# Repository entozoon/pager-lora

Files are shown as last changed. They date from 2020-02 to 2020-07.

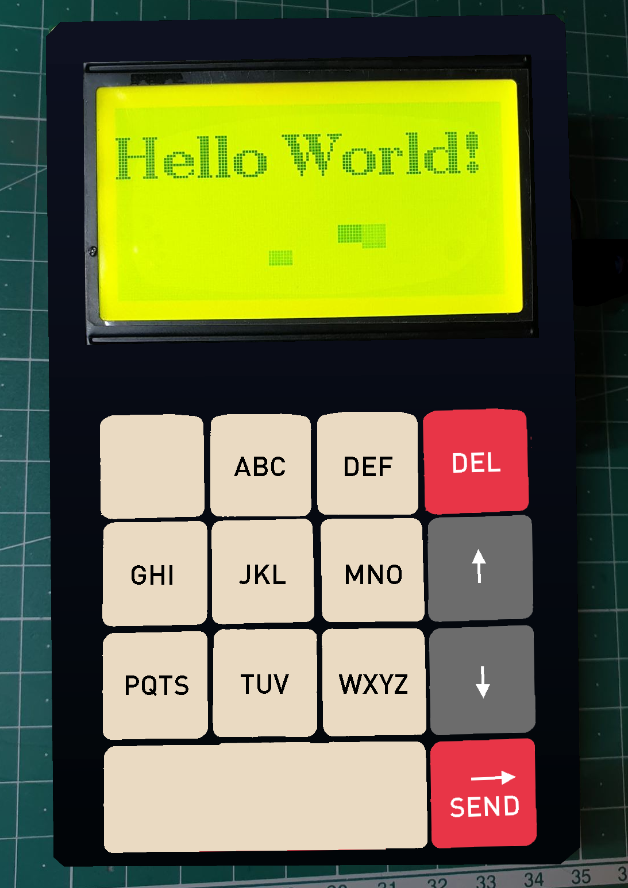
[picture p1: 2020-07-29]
mk-ii-chokia/hardware/design-1.png

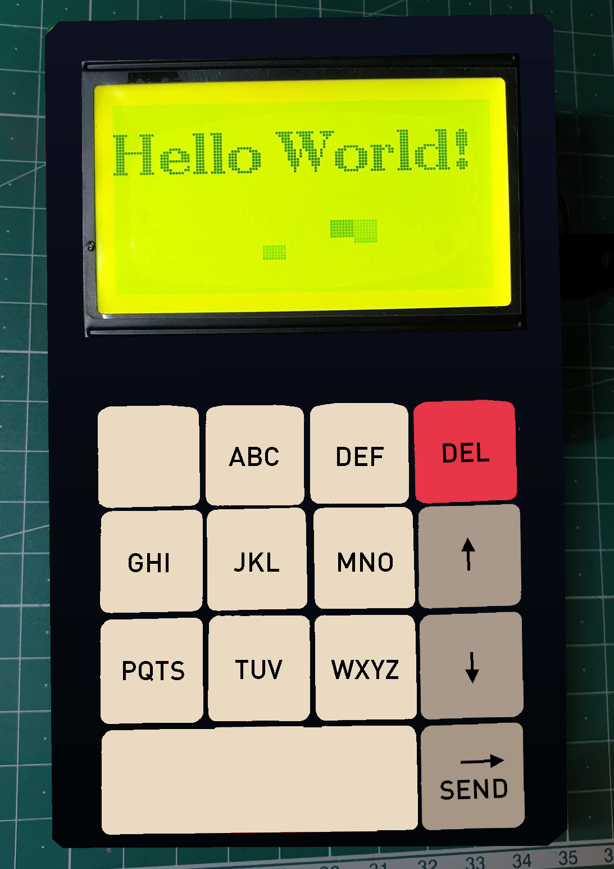
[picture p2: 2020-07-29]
mk-ii-chokia/hardware/design-5.png

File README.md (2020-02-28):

# Pager Lora

## Ingredients

- Arduino / ESP8266 ?
  Arduino is more conservative but doesn't seem to be the popular choice. I mean, speed might be an issue with transmission so bang it out on a Wemos with WIFI disabled.

## Goals

- Clamshell
- Nokia 5110 screen / e-ink
- Buzz tune on receipt
- Opening wakes up device screen
- Small as poss, but poss 18520 batteries, so..
- Lora communication over 300m

## Input

Mobile keypad text is a fun way to go. Revive that old skill.

### Drawing?

Would be nice, but bandwidth is limited, as well as rendering capabilities so.. it'd be a whole thing. Couldn't be real-time.. but still an option if I make a larger device.

## Comms

| Send Device | Listen Device | User |
| --- | :---: | ---: |
| Listening always | Listening always | |
| | | |
| Emit (n?) | | Send |
| | Receive | Buzz |
| | Store to EEPROM | |
| | Emit message received? meh | |
| Stop emitting | | |
| | Screen on, display message | Open device |
| | | |

## Power

The power concerns are real. So let's make sure to do all dis:

### Disable WIFI on microcontroller

`WiFi.mode(WIFI_OFF);`

### Sleep

If possible, I mean perhaps it could sleep half the time? Let's have a shufty at some power requirements. Complete conjecture, but anyways:

- Microcontroller
  General: 20mA ESP w/out WIFI or 5mA for pro mini
  Sleep: Negligible

- LoRa (3.3v)
  Receiver: ≦ 10mA (LnaBoost off, band 1)
  Transmit: ≦ 120mA (+ 20dBm)
  Sleep: Negligible
  Total, if listening always and transmitting like 1% of the time: 11mA

- Screen
  Unlit: 1mA
  Backlit: <= 80mA, so maybe don't bother!

- 18650 2400mah 3.7v
  5v converters are supposedly 90% efficient so 2160mAh

So, assuming they're always listening and transmit at glorious 28.8kbps modem style speed now and then:

    Battery capacity (mA/h) / Current draw (mA) = hours of battery life  .. right?

    2160mAh / 32mA = 67 hours
    900mAh / 32mA = 28 hours
    240mAh / 32mA = 7.5 hours

Woah. I mean, these are conservative numbers too. Not three bad.
So yeah, sleep both chips if possible when closed and poss use an Arduino (5mA).

### C rating?

Literally anything is fine.
Peak current, with lit screen and full transmit is like 220mA, so 0.5C @ 500mA is enough. (18650 are 1C)

### Sleep LoRa chip

Just a reminder to sleep this along with the microcontroller.

## Battery

5V step ups bitch out under .5v, which won't matter much, but the efficiency varies with input voltage (and current): http://www.hobbytronics.co.uk/u1v10f5-5v-regulator

| Battery | V |  mAh | Effic | ->~mAh | Life(h) mAh/32mA | Notes |
| --- | ---: | ---: | ----: | -----: | ---: | --- |
| AAA (r/c) | 1.5v | 1000 |  @70% | 700 | 22 | |
| AAA (r/c) x2 | 1.5v | 2000 |  @70% | 1400 | 44 | |
| AA (r/c) | 1.5v | 2400 |  @70% | 1680 | 53 | |
| Lipo 50x30mm | 3.7v | 2000 |  @90% | 1800 | 56 | Better form factor than AA |
| 18650 | 3.7v | 2400 |  @90% | 2160 | 66 | All lipos easy to charge |
| Lipo 90x60mm | 3.7v | 4000 |  @90% | 3600 | 113 | Phone bat size, affordable |

Lipo batteries supposedly self-disarge at only 5%/month (despite my experience), not far off alkaline.
So any lipo really, high mAh as possible for the best form factor.
But deeefinitely invest in a voltmeter setup (see below). Perhaps flash the screen hard and/or chirp for a turn off.

## Battery monitoring

Feed battery into analogue input, with a voltage divider to reduce it.

Wemos A0 has a voltage divider built in. 220k / 100k (2/3rdsness).
People say it has a range of 3.3V, but I should test that.

    +++++++++
        |
      [10k]
        |
        |----(100pF -> 1nF)---> analogue input
        |    reduce wobble? Didn't work..
        |
      [10k]
        |
    ---------

    V divideness = (R1 / R1 + R2)
                 = 1 / 2

So if my lipo spits out a mad 4.6V, A0 would receive 2.3V.
Update: 1024 max value is 6.1V, in reality, through my divider.

| Lipo V | Desc | Dividered | A0 (theory) | Human  |
| --- | --- | ---: | ---: | --- |
| 4.6 | Pumped | 2.3 | 713 | 100% |
| 4.2 | Full | 2.1 | 652 | 100% |
| 4 | Good | 2 | 621 | 75% |
| 3.86 | Mid | 1.93 | 599 | 50% |
| 3.75 | Low | 1.875 | 582 | 20% !  |
| 3.7 | Low | 1.85 | 574 | 10% !  |
| 3.5 | Dead | 1.75 | 543 | 0% off |

    A0 (theory) = Dividered V / 3.3 * 1024

Empirical realities are close but a little different:

| Lipo V | Desc | A0 (theory) | Human  |
| --- | --- | ---: | --- |
| 4.6 | Pumped | 762 | 100% |
| 4.2 | Full | 706 | 100% |
| 4 | Good | 660 | 75% |
| 3.86 | Mid | 634 | 50% |
| 3.75 | Low | 615 | 20% !  |
| 3.7 | Low | 608 | 10% !  |
| 3.5 | Dead | 577 | 0% off |

## Power off

It really should power itself off, LoRa et al, with low batt for safety. Might not be worth it though, I mean, do my charge protection circuits handle that? Probs eh?

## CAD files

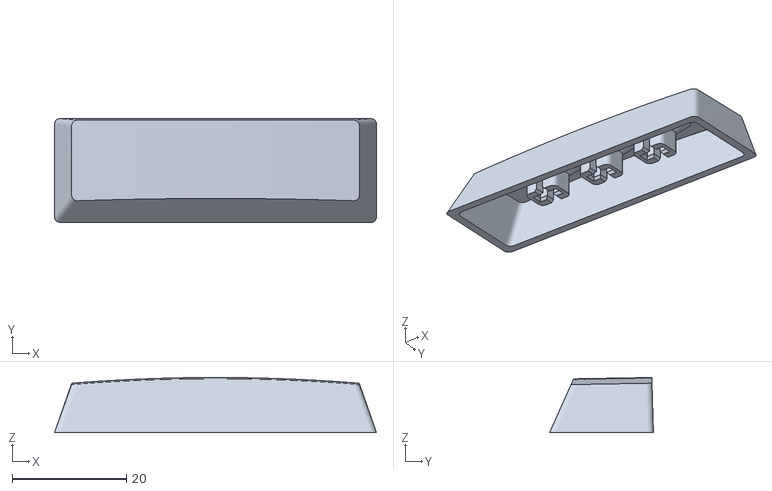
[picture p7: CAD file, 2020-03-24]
mk-ii-chokia/hardware/keycaps/chokia-spacebar.stl
56.3 x 18.2 x 9.62

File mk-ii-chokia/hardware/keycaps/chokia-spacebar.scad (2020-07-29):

// the point of this file is to be a sort of DSL for constructing keycaps.
// when you create a method chain you are just changing the parameters
// key.scad uses, it doesn't generate anything itself until the end. This
// lets it remain easy to use key.scad like before (except without key profiles)
// without having to rely on this file. Unfortunately that means setting tons of
// special variables, but that's a limitation of SCAD we have to work around

use <src/key.scad>

include <src/settings.scad>
include <src/key_sizes.scad>
include <src/key_profiles.scad>
include <src/key_types.scad>
include <src/key_transformations.scad>

//https://github.com/rsheldiii/KeyV2/blob/master/src/settings.scad

//$has_brim=true;
$inverted_dish = true;
$key_length = 3;
$stem_inset = 2;

$key_shape_type = "rounded_square"; // iso_enter sculpted_square rounded_square square oblong

$stabilizer_type = "cherry_stabilizer"; // [costar_stabilizer, cherry_stabilizer, disable]

// be reet, use the outside two?
// $stabilizers = $key_length >= 6 ? [[-50, 0], [50, 0]] : $key_length >= 2 ? [[-12,0],[12,0]] : [];

//$rounded_key = true; // good but intense

 dcs_row(1) {
     $dish_type =  "sideways cylindrical";
     key();
 }

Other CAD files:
mk-ii-chokia/hardware/keycaps/src/settings.scad
mk-ii-chokia/hardware/keycaps/customizer.scad
mk-ii-chokia/hardware/keycaps/customizer_base.scad
mk-ii-chokia/hardware/keycaps/key_mold.scad
mk-ii-chokia/hardware/keycaps/keys.scad
mk-ii-chokia/hardware/keycaps/keysets.scad
mk-ii-chokia/hardware/keycaps/model_base.scad
mk-ii-chokia/hardware/keycaps/src/dishes.scad
mk-ii-chokia/hardware/keycaps/src/dishes/cylindrical.scad
mk-ii-chokia/hardware/keycaps/src/dishes/old_spherical.scad
mk-ii-chokia/hardware/keycaps/src/dishes/sideways_cylindrical.scad
mk-ii-chokia/hardware/keycaps/src/dishes/spherical.scad
mk-ii-chokia/hardware/keycaps/src/features/key_bump.scad
mk-ii-chokia/hardware/keycaps/src/functions.scad
mk-ii-chokia/hardware/keycaps/src/key.scad
mk-ii-chokia/hardware/keycaps/src/key_features.scad
mk-ii-chokia/hardware/keycaps/src/key_profiles.scad
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

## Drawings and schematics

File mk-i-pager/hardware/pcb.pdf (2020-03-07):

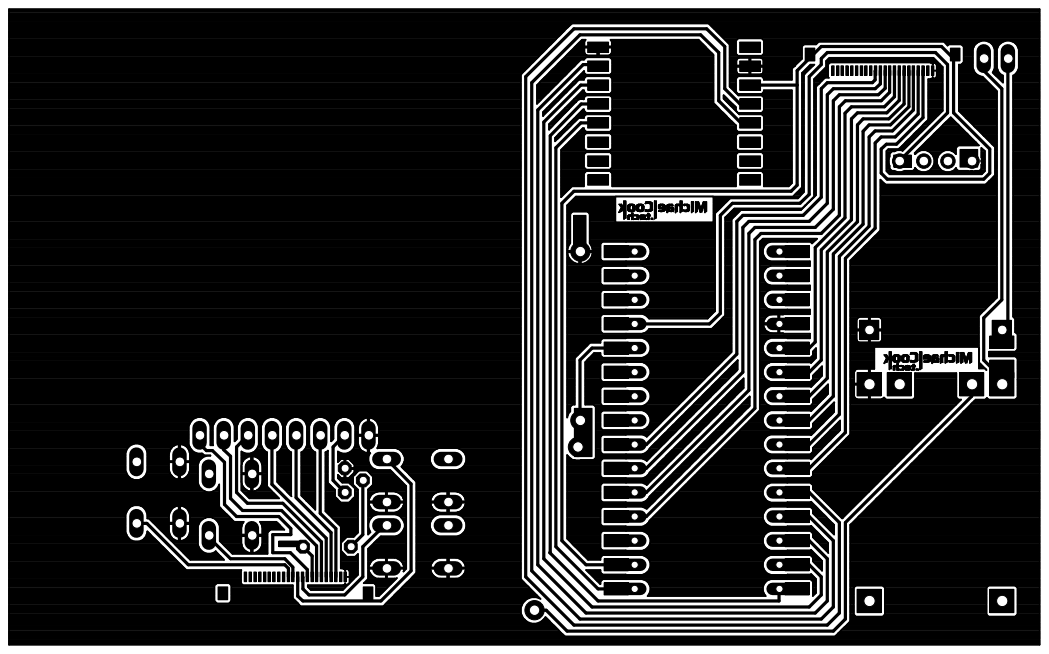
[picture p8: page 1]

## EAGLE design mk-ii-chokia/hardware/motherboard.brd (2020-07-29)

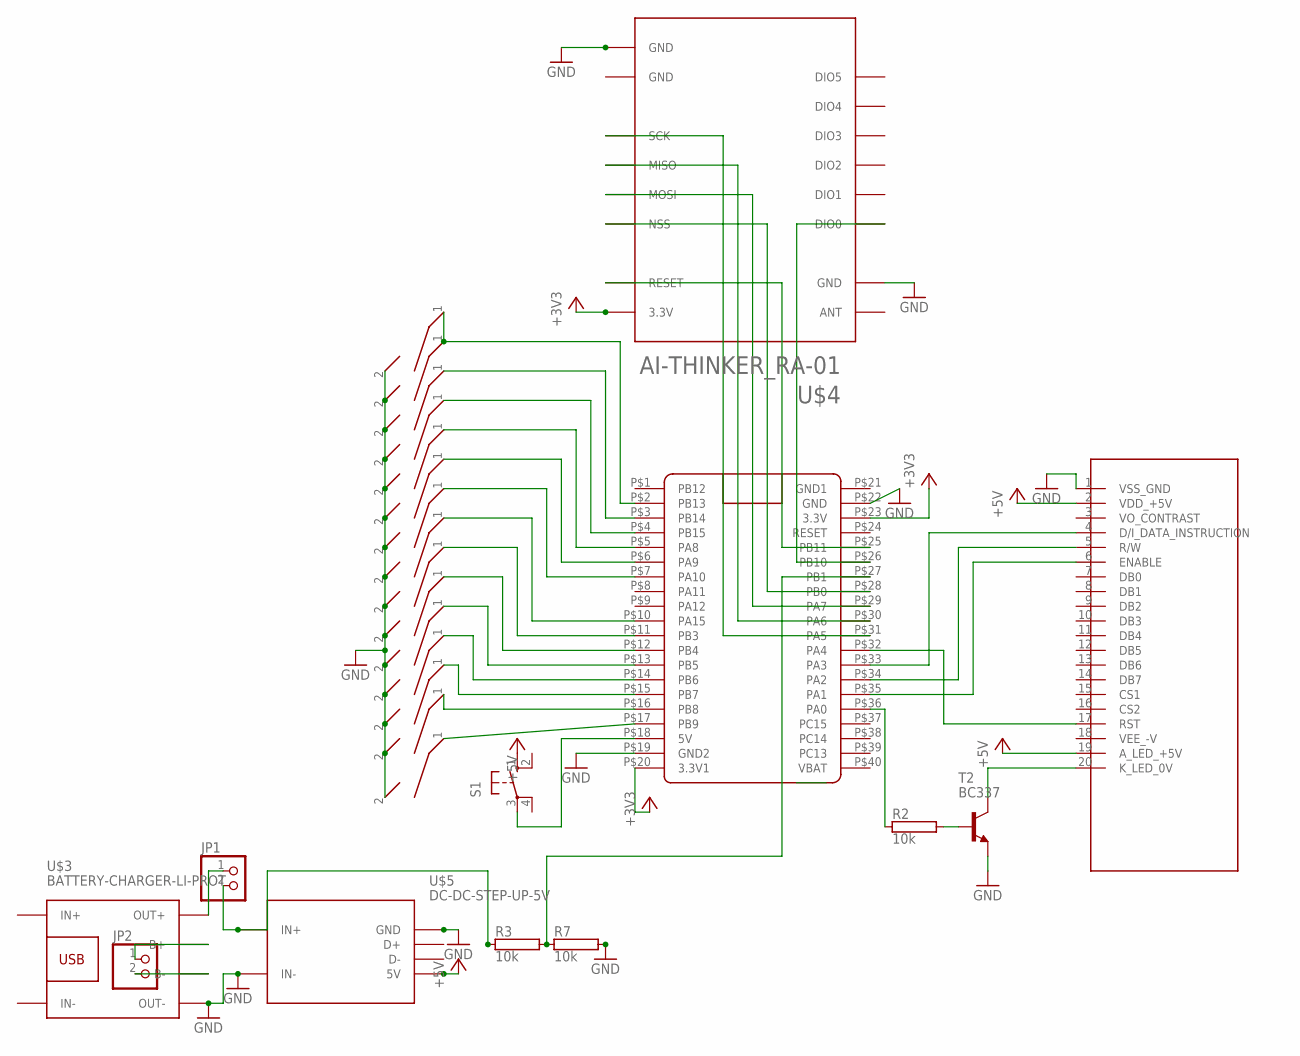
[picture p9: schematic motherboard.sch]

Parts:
JP1, JP2: PINHD-1X2/90; 1X02/90
R2, R3, R7: 10k; AC01
S1: 10-XX; B3F-10XX
SW1, SW2, SW3, SW4, SW5, SW6, SW7, SW8, SW9, SW10, SW11, SW12, SW13, SW14, SW15: CHERRY_MX; MX1A-XXNN
T2: BC337; TO92
U$1: W12864
U$2: BLUE_PILL
U$3: BATTERY-CHARGER-LI-PROT
U$4: AI-THINKER_RA-01
U$5: DC-DC-STEP-UP-5V

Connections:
+3V3: U$2.P$20 (3.3V1), U$2.P$23 (3.3V), U$4.P$3 (3.3V)
+5V: S1.1 (S), U$1.2 (VDD_+5V), U$1.19 (A_LED_+5V), U$5.5V
GND: R7.2, SW1.2, SW2.2, SW3.2, SW4.2, SW5.2, SW6.2, SW7.2, SW8.2, SW9.2, SW10.2, SW11.2, SW12.2, SW13.2, SW14.2, SW15.2, T2.1 (E), U$1.1 (VSS_GND), U$2.P$19 (GND2), U$2.P$22 (GND), U$3.OUT-, U$4.P$2 (GND), U$4.P$16 (GND), U$5.GND, U$5.IN-
GND1: U$2.P$21 (GND1)
unnamed: JP1.1, U$3.OUT+
unnamed: U$2.P$25 (PB11), U$4.P$4 (RESET)
unnamed: U$2.P$28 (PB0), U$4.P$15 (NSS)
unnamed: U$2.P$29 (PA7), U$4.P$14 (MOSI)
unnamed: U$2.P$30 (PA6), U$4.P$13 (MISO)
unnamed: U$2.P$31 (PA5), U$4.P$12 (SCK)
unnamed: U$2.P$26 (PB10), U$4.P$5 (DIO0)
unnamed: U$1.6 (ENABLE), U$2.P$35 (PA1)
unnamed: U$1.5 (R/W), U$2.P$34 (PA2)
unnamed: U$1.17 (RST), U$2.P$32 (PA4)
unnamed: U$1.4 (D/I_DATA_INSTRUCTION), U$2.P$33 (PA3)
unnamed: R2.2, T2.2 (B)
unnamed: T2.3 (C), U$1.20 (K_LED_0V)
unnamed: SW1.1, U$2.P$17 (PB9)
unnamed: JP1.2, R3.1, U$5.IN+
unnamed: SW2.1, U$2.P$16 (PB8)
unnamed: R2.1, U$2.P$36 (PA0)
unnamed: SW3.1, U$2.P$15 (PB7)
unnamed: SW4.1, U$2.P$14 (PB6)
unnamed: SW5.1, U$2.P$13 (PB5)
unnamed: SW6.1, U$2.P$12 (PB4)
unnamed: SW7.1, U$2.P$11 (PB3)
unnamed: R3.2, R7.1, U$2.P$27 (PB1)
unnamed: SW8.1, U$2.P$10 (PA15)
unnamed: SW9.1, U$2.P$7 (PA10)
unnamed: SW10.1, U$2.P$6 (PA9)
unnamed: SW13.1, U$2.P$3 (PB14)
unnamed: SW14.1, SW15.1, U$2.P$2 (PB13)
unnamed: SW11.1, U$2.P$5 (PA8)
unnamed: SW12.1, U$2.P$4 (PB15)
unnamed: JP2.1, U$3.B+
unnamed: JP2.2, U$3.B-
unnamed: S1.3, U$2.P$18 (5V)

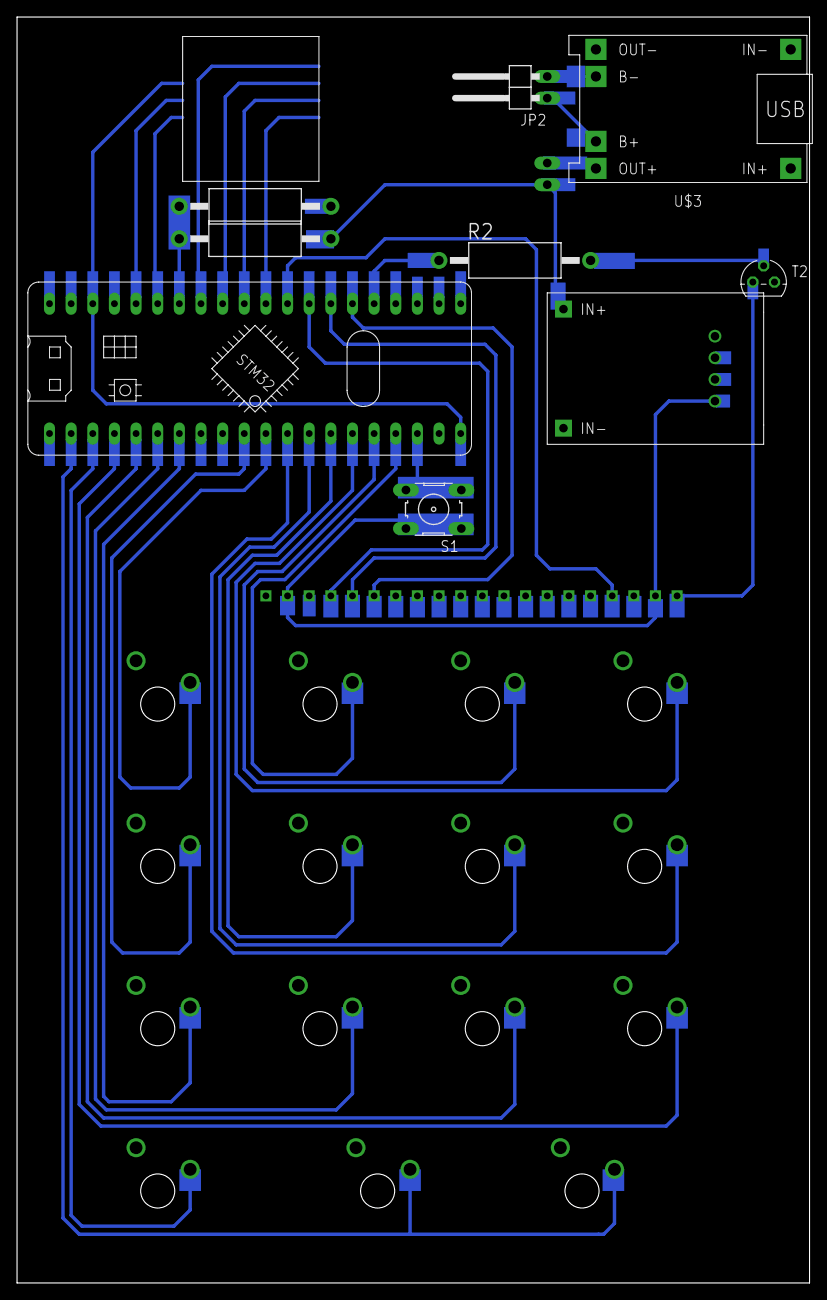
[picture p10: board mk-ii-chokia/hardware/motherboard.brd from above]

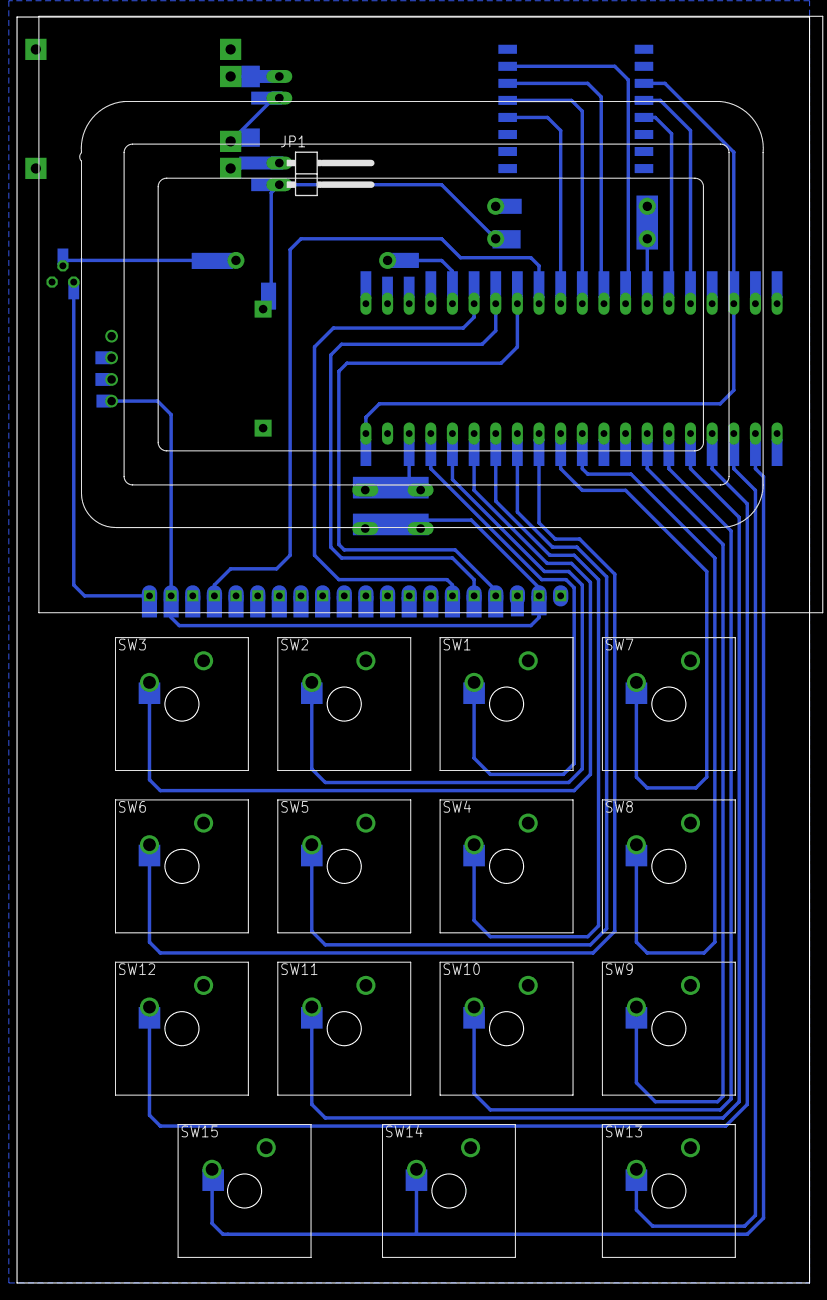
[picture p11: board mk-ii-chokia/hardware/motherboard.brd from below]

Board: 2 copper layers, 93.0 x 148.6 mm, 27 parts (17 on the bottom side), 36 nets.

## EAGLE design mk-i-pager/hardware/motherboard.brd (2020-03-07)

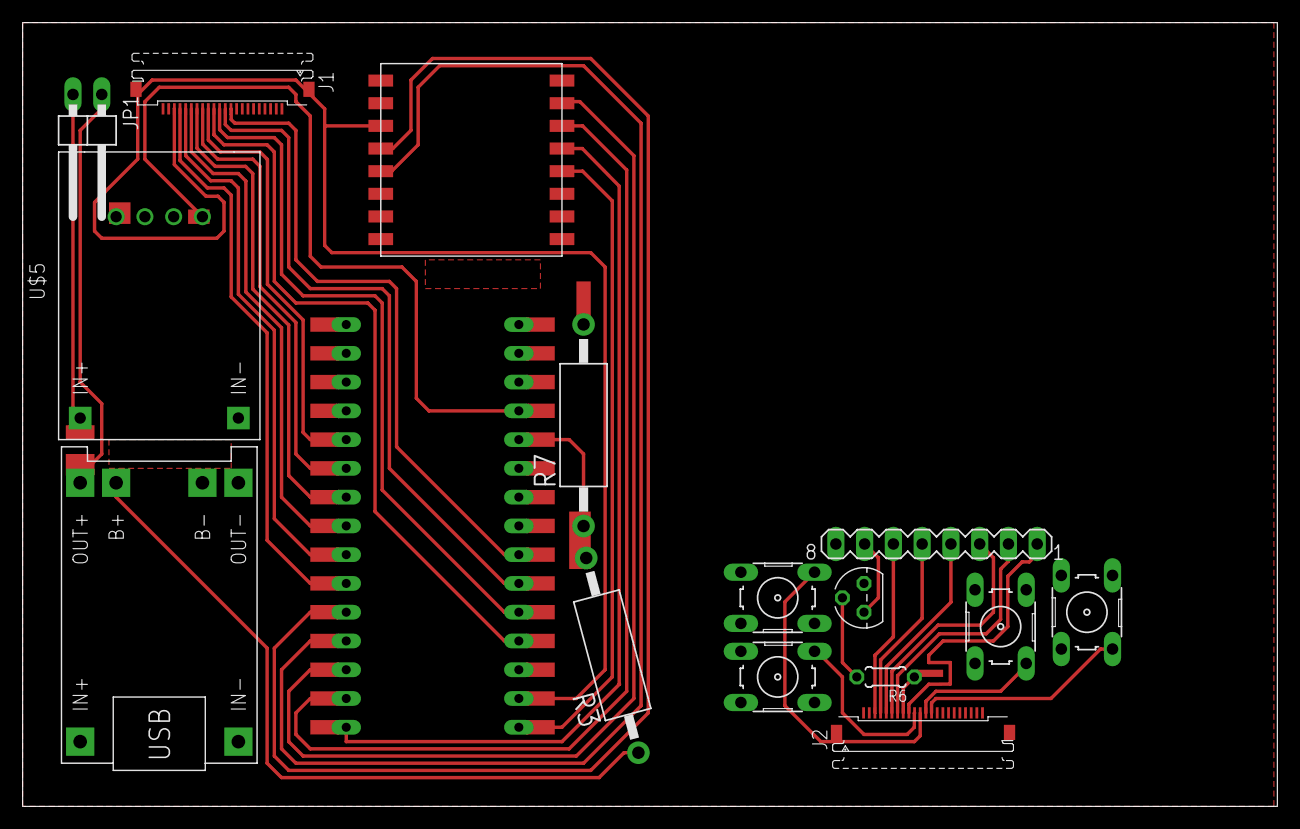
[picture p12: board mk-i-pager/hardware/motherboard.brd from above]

Board: 2 copper layers, 110.8 x 69.2 mm, 16 parts (0 on the bottom side), 36 nets.

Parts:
DIS2: NOKIA5110
J1, J2: XF2L-2235-1
JP1: 1X02/90
R3, R7: 10k; AC01
R6: 10k; 0204/5
S1, S2, S3, S4: B3F-10XX
T1: BC337; TO92
U$1: NANO
U$3: BATTERY-CHARGER-LI-PROT
U$4: AI-THINKER_RA-01
U$5: DC-DC-STEP-UP-5V

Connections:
+3V3: J1.20, U$1.3.3V, U$4.P$3
+5V: U$1.5V, U$5.5V
GND: DIS2.8, J1.22, J2.1, R7.2, S1.1, S1.2, S2.1, S2.2, S3.1, S3.2, S4.1, S4.2, T1.1, U$1.GND1, U$3.OUT-, U$4.P$2, U$4.P$16, U$5.GND, U$5.IN-
unnamed: JP1.1, U$3.OUT+
unnamed: U$1.D13, U$4.P$12
unnamed: J1.19, U$1.D7
unnamed: U$1.D12, U$4.P$13
unnamed: U$1.D11, U$4.P$14
unnamed: U$1.D10, U$4.P$15
unnamed: U$1.D9, U$4.P$5
unnamed: U$1.D8, U$4.P$4
unnamed: J1.14, U$1.D2
unnamed: J1.18, U$1.D6
unnamed: J1.17, U$1.D5
unnamed: J1.16, U$1.D4
unnamed: J1.15, U$1.D3
unnamed: R6.2, T1.2
unnamed: JP1.2, U$5.IN+
unnamed: R3.1, U$3.B+
unnamed: DIS2.1, J2.9
unnamed: J2.8, R6.1
unnamed: J2.10, S1.3
unnamed: J2.11, S2.3
unnamed: J2.12, S3.3
unnamed: DIS2.7, T1.3
unnamed: R3.2, R7.1, U$1.A7
unnamed: DIS2.6, J2.3
unnamed: DIS2.5, J2.4
unnamed: DIS2.4, J2.5
unnamed: DIS2.3, J2.6
unnamed: DIS2.2, J2.7
unnamed: J2.13, S4.3
unnamed: J1.13, U$1.A0
unnamed: J1.12, U$1.A1
unnamed: J1.11, U$1.A2
unnamed: J1.10, U$1.A3

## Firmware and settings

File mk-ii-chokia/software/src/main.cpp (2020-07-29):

#include <Arduino.h>
#include <U8g2lib.h>
#include <SPI.h>
#include <Wire.h>

// //
// // BLINK
// //
// void setup()
// {
//   pinMode(LED_BUILTIN, OUTPUT);
// }
// void loop()
// {
//   digitalWrite(LED_BUILTIN, HIGH); // turn the LED on (HIGH is the voltage level)
//   delay(200);                      // wait for a second
//   digitalWrite(LED_BUILTIN, LOW);  // turn the LED off by making the voltage LOW
//   delay(200);                      // wait for a second
// }

//
// LCD Test
//
U8G2_ST7920_128X64_1_SW_SPI u8g2(
    U8G2_R0, // rotation
    PA1,     // Clock "E" enable?
    PA2,     // Data "R/W" might have this and next wrong way.. but meh
    PA3,     // CS "RS" "D"
    PA4      // Reset "RST"
);
// Also connect +5v to VCC, BLA
// and - to GND, PSB, BLK
void setup(void)
{
  delay(10000);         // ALWAYS delay or it can't be reprogrammed easily. Press reset during build
  pinMode(PA0, OUTPUT); // dim
  u8g2.begin();
}
void loop(void)
{
  analogWrite(PA0, 255);
  u8g2.firstPage();
  do
  {
    // https://github.com/olikraus/u8g2/wiki/u8g2reference
    u8g2.setFont(u8g2_font_ncenB14_tr);
    u8g2.drawStr(0, 24, "Hello World!");
    // Can't bleeding get it to output a random string
    // char alphabet[] = {"ABCDEFGHIJKLMNOPQRSTUVWXYZ"};
    // char char_array[] = {""};
    // char_array[0] = char(random(0, 9));
    // // strcpy(char_array, alphabet[random(0, 25)].c_str());
    // u8g2.drawStr(40, 50, char_array);
    u8g2.drawBox(random(0, 100), random(30, 50), 8, 8);
    // Not amazing, then again I've no idea what the page system is so..
  } while (u8g2.nextPage());
}

// //
// // Backlight dimming test
// //
// void setup()
// {
//   Serial.begin(9600);
//   delay(10000); // ALWAYS delay or it can't be reprogrammed easily. Press reset during build
//   pinMode(PA0, OUTPUT);
// }
// float x = 0;
// float pi = 3.141592;
// void loop()
// {
//   // if (x > 255)
//   //   x = 0;
//   // Serial.print(x);
//   // Serial.print(' ');
//   // analogWrite(9, x);
//   // delay(20);
//   // x++;
//   if (x > 4 * pi)
//     x = 0;
//   int y = floor(255 * ((sin(x / 2 - pi / 2)) / 2 + .5));
//   // Serial.print(y);
//   // Serial.print(' ');
//   analogWrite(PA0, y);
//   x += 0.01;
//   delay(5);
// }

// //
// // RECEIVE
// //
// #include <SPI.h>
// #include <LoRa.h>
// void setup()
// {
//   Serial.begin(9600);
//   delay(10000); // for uploading to device
//   Serial.println("\nLoRa Receiver");
//   //          (nss, reset, dio0); (dio0 unused)
//   // LoRa.setPins(10, 9);
//   LoRa.setPins(PB0, PB11); //, PB10);  // only sending..
//   if (!LoRa.begin(433E6)) // 433 is legal in the UK and capable by device. 863-870 otherwise. worried it'll clash though
//   {
//     Serial.println("Starting LoRa failed!");
//     while (1)
//       ;
//   }
// }
// void loop()
// {
//   // try to parse packet
//   int packetSize = LoRa.parsePacket();
//   if (packetSize)
//   {
//     // received a packet
//     Serial.print("Received packet '");
//     // read packet
//     while (LoRa.available())
//     {
//       Serial.print((char)LoRa.read());
//     }
//     // print RSSI of packet
//     Serial.print("' with RSSI "); // Received Signal Strength Indicator (0 is theoretical full strength)
//     Serial.println(LoRa.packetRssi());
//   }
// }

// //
// // SEND
// //
// #include <SPI.h>
// #include <LoRa.h>
// int counter = 0;
// void setup()
// {
//   delay(10000); // for uploading to device
//   Serial.begin(9600);
//   Serial.println("\nLoRa Sender");
//   //          (nss, reset, dio0); (dio0 unused)
//   LoRa.setPins(PB0, PB11); //, PB10);  // only sending..
//   if (!LoRa.begin(433E6)) // 433 is legal in the UK and capable by device. 863-870 otherwise. worried it'll clash though
//   {
//     Serial.println("Starting LoRa failed!");
//     while (1)
//       ;
//   }
// }
// void loop()
// {
//   Serial.print("Sending packet: ");
//   Serial.println(counter);
//   // send packet
//   LoRa.beginPacket();
//   LoRa.print("hey from chokia ");
//   LoRa.print(counter);
//   LoRa.endPacket();
//   counter++;
//   delay(1000);
// }

// //
// // SENDY RECEIVY
// //
// #include <SPI.h>
// #include <LoRa.h>
// long counter = 0;
// long ticker = 0;
// long tickerSnapshot = 0;
// void setup()
// {
//   delay(15000); // for uploading to device
//   Serial.begin(9600);
//   Serial.println("\nLoRa Receiver");
//   //          (nss, reset, dio0); (dio0 unused)
//   // LoRa.setPins(PB0, PB1); //, PA4); // only sending..
//   LoRa.setPins(PB0, PB11); //, PB10);  // only sending..
//   if (!LoRa.begin(433E6))  // 433 is legal in the UK and capable by device. 863-870 otherwise. worried it'll clash though
//   {
//     Serial.println("Starting LoRa failed!");
//     while (1)
//       ;
//   }
// }
// void loop()
// {
//   // try to parse packet
//   int packetSize = LoRa.parsePacket();
//   if (packetSize)
//   {
//     // received a packet
//     Serial.print("Received: '");
//     // read packet
//     while (LoRa.available())
//     {
//       Serial.print((char)LoRa.read());
//     }
//     // print RSSI of packet
//     Serial.print("' with RSSI "); // Received Signal Strength Indicator (0 is theoretical full strength)
//     Serial.println(LoRa.packetRssi());
//     // delay(10);
//   }

//   if (ticker > 5000)
//   {
//     tickerSnapshot = millis();
//     Serial.print("Sending: ");
//     Serial.println(counter);
//     // send packet
//     LoRa.beginPacket();
//     LoRa.print("Hey from chokia ");
//     LoRa.print(counter);
//     LoRa.endPacket();
//     counter++;
//     // delay(10);
//   }
//   ticker = millis() - tickerSnapshot;
// }

//
// Button test
// (Complete garbage of course. Need to properly key scan, I think?)
//
// void setup()
// {
//   delay(10000);
//   Serial.begin(9600);
//   pinMode(PB9, INPUT_PULLUP);
//   pinMode(PB8, INPUT_PULLUP);
//   pinMode(PB7, INPUT_PULLUP);
//   pinMode(PB6, INPUT_PULLUP);
//   pinMode(PB5, INPUT_PULLUP);
//   pinMode(PB4, INPUT_PULLUP);
//   pinMode(PB3, INPUT_PULLUP);
//   pinMode(PA15, INPUT_PULLUP);
//   // PA11
//   // PA12 explode it (USB)
//   pinMode(PA10, INPUT_PULLUP);
//   pinMode(PA9, INPUT_PULLUP);
//   pinMode(PA8, INPUT_PULLUP);
//   pinMode(PB15, INPUT_PULLUP);
//   pinMode(PB14, INPUT_PULLUP);
//   pinMode(PB13, INPUT_PULLUP);
//   pinMode(PB12, INPUT_PULLUP);
// }
// void loop()
// {
//   if (digitalRead(PB9) == 0)
//   {
//     Serial.println("PB9");
//   }
//   if (digitalRead(PB8) == 0)
//   {
//     Serial.println("PB8");
//   }
//   if (digitalRead(PB7) == 0)
//   {
//     Serial.println("PB7");
//   }
//   if (digitalRead(PB6) == 0)
//   {
//     Serial.println("PB6");
//   }
//   if (digitalRead(PB5) == 0)
//   {
//     Serial.println("PB5");
//   }
//   if (digitalRead(PB4) == 0)
//   {
//     Serial.println("PB4");
//   }
//   if (digitalRead(PB3) == 0)
//   {
//     Serial.println("PB3");
//   }
//   if (digitalRead(PA15) == 0)
//   {
//     Serial.println("PA15");
//   }
//   if (digitalRead(PA10) == 0)
//   {
//     Serial.println("PA10");
//   }
//   if (digitalRead(PA9) == 0)
//   {
//     Serial.println("PA9");
//   }
//   if (digitalRead(PA8) == 0)
//   {
//     Serial.println("PA8");
//   }
//   if (digitalRead(PB15) == 0)
//   {
//     Serial.println("PB15");
//   }
//   if (digitalRead(PB14) == 0)
//   {
//     Serial.println("PB14");
//   }
//   if (digitalRead(PB13) == 0)
//   {
//     Serial.println("PB13");
//   }
//   if (digitalRead(PB12) == 0)
//   {
//     Serial.println("PB12");
//   }
// }

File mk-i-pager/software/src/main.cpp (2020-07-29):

#include <Arduino.h>

#include <SPI.h>
#include <Adafruit_GFX.h>
#include <Adafruit_PCD8544.h>
#include <Fonts/FreeSans9pt7b.h>
#include <Fonts/Tiny3x3a2pt7b.h>
#include <Fonts/Org_01.h>
#include <Fonts/Picopixel.h>
#include <Fonts/TomThumb.h>
#include <nokia-myke.h>

// //
// // BLINK
// //
// void setup()
// {
//   pinMode(LED_BUILTIN, OUTPUT);
// }
// void loop()
// {
//   digitalWrite(LED_BUILTIN, HIGH); // turn the LED on (HIGH is the voltage level)
//   delay(200);                      // wait for a second
//   digitalWrite(LED_BUILTIN, LOW);  // turn the LED off by making the voltage LOW
//   delay(200);                      // wait for a second
// }

// //
// // SEND
// //
// #include <SPI.h>
// #include <LoRa.h>
// int counter = 0;
// void setup()
// {
//   delay(4000); // for uploading to device
//   Serial.begin(9600);
//   Serial.println("\nLoRa Sender");
// //         (nss, reset, dio0); (dio0 unused)
// //         (D10, D8, D9);
// LoRa.setPins(10, 8);
//   if (!LoRa.begin(433E6)) // 433 is legal in the UK and capable by device. 863-870 otherwise. worried it'll clash though
//   {
//     Serial.println("Starting LoRa failed!");
//     while (1)
//       ;
//   }
// }
// void loop()
// {
//   Serial.print("Sending packet: ");
//   Serial.println(counter);
//   // send packet
//   LoRa.beginPacket();
//   LoRa.print("hey from pager ");
//   LoRa.print(counter);
//   LoRa.endPacket();
//   counter++;
//   delay(1000);
// }

// //
// // RECEIVE
// //
// #include <SPI.h>
// #include <LoRa.h>
// void setup()
// {
//   delay(4000); // for uploading to device
//   Serial.begin(9600);
//   Serial.println("\nLoRa Receiver");
//   //          (nss, reset, dio0); (dio0 unused)
//   //          (D10, D8, D9);
//   LoRa.setPins(10, 8);
//   if (!LoRa.begin(433E6)) // 433 is legal in the UK and capable by device. 863-870 otherwise. worried it'll clash though
//   {
//     Serial.println("Starting LoRa failed!");
//     while (1)
//       ;
//   }
// }
// void loop()
// {
//   // try to parse packet
//   int packetSize = LoRa.parsePacket();
//   if (packetSize)
//   {
//     // received a packet
//     Serial.print("Received packet '");
//     // read packet
//     while (LoRa.available())
//     {
//       Serial.print((char)LoRa.read());
//     }
//     // print RSSI of packet

//     Serial.print("' with RSSI "); // Received Signal Strength Indicator (0 is theoretical full strength)
//     Serial.println(LoRa.packetRssi());
//   }
// }

// // TEST VOLTMETER READ
// void setup()
// {
//   Serial.begin(9600);
//   delay(4000);
// }
// void loop()
// {
//   int val = analogRead(A0);
//   Serial.println(val);
//   delay(100);
// }

// //
// // SENDY RECEIVY (MEAT)
// //
// #include <SPI.h>
// #include <LoRa.h>
// long counter = 0;
// long ticker = 0;
// long tickerSnapshot = 0;
// void setup()
// {
//   delay(15000); // for uploading to device
//   Serial.begin(9600);
//   Serial.println("\nLoRa Receiver");
//   //          (nss, reset, dio0); (dio0 unused)
//   //          (D10, D8, D9);
//   LoRa.setPins(10, 8);
//   if (!LoRa.begin(433E6)) // 433 is legal in the UK and capable by device. 863-870 otherwise. worried it'll clash though
//   {
//     Serial.println("Starting LoRa failed!");
//     while (1)
//       ;
//   }
// }
// void loop()
// {
//   // try to parse packet
//   int packetSize = LoRa.parsePacket();
//   if (packetSize)
//   {
//     // received a packet
//     Serial.print("Received: '");
//     // read packet
//     while (LoRa.available())
//     {
//       Serial.print((char)LoRa.read());
//     }
//     // print RSSI of packet
//     Serial.print("' with RSSI "); // Received Signal Strength Indicator (0 is theoretical full strength)
//     Serial.println(LoRa.packetRssi());
//     // delay(10);
//   }

//   if (ticker > 10000)
//   {
//     tickerSnapshot = millis();
//     Serial.print("Sending: ");
//     Serial.println(counter);
//     // send packet
//     LoRa.beginPacket();
//     LoRa.print("Hey from pager ");
//     LoRa.print(counter);
//     // dies here! *****
//     LoRa.endPacket();
//     counter++;
//     // delay(1000);
//   }
//   ticker = millis() - tickerSnapshot;
// }
//
//
// LCD Test
//
// Software SPI (slower updates, more flexible pin options):
// pin 7 - Serial clock out (SCLK)
// pin 6 - Serial data out (DIN)
// pin 5 - Data/Command select (D/C)
// pin 4 - LCD chip select (CS)
// pin 3 - LCD reset (RST)
//                                         (clk, din, dc, ce, rst)
Adafruit_PCD8544 display = Adafruit_PCD8544(7, 6, 5, 4, 2);
// Hardware SPI (faster, but must use certain hardware pins):
// SCK is LCD serial clock (SCLK) - this is pin 13 on Arduino Uno
// MOSI is LCD DIN - this is pin 11 on an Arduino Uno
// pin 5 - Data/Command select (D/C)
// pin 4 - LCD chip select (CS)
// pin 3 - LCD reset (RST)
// Adafruit_PCD8544 display = Adafruit_PCD8544(5, 4, 3);
// Note with hardware SPI MISO and SS pins aren't used but will still be read
// and written to during SPI transfer.  Be careful sharing these pins!
void setup()
{
  delay(5000);
  display.begin();
  display.setContrast(60);
  display.setRotation(2);
  display.setFont(&__nokiafc224pt7b);
  display.setTextColor(BLACK);
  display.setTextSize(1);
}
void loop()
{
  display.clearDisplay();
  display.setCursor(0, 10);
  display.println("3");
  display.println("messages");
  display.println("received");
  display.display();
  delay(1000);
}

// //
// // Backlight dimming test
// //
// // Not quite sure about this.. I heard a 39ohm resistor to gpio could control it. dimming on would be ace
// // but - don't stress too much, if it's just on all the tiem that'd be okay too
// // https://www.algissalys.com/electronics/nokia-5110-lcd-backlight-to-ground-using-gpio
// int pinDim = 3;
// void setup()
// {
//   Serial.begin(9600);
//   delay(5000);
//   // I think D1, D2, are 1, 2.. A0, A1 are A0, A1..
//   pinMode(pinDim, OUTPUT);
// }
// float x = 0;
// float pi = 3.141592;
// void loop()
// {
//   // if (x > 255)
//   //   x = 0;
//   // Serial.print(x);
//   // Serial.print(' ');
//   // analogWrite(9, x);
//   // delay(20);
//   // x++;
//   if (x > 4 * pi)
//     x = 0;
//   int y = floor(255 * ((sin(x / 2 - pi / 2)) / 2 + .5));
//   // Serial.print(y);
//   // Serial.print(' ');
//   analogWrite(pinDim, y);
//   x += 0.01;
//   delay(5);
// }

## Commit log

2019-12-13 Worked out the whole battery theory lolol
2020-02-27 Tried to get arduino-lmic going, and it seems to be.. but nothing receiving
2020-02-27 It works! Sending and receiving!! with a range of like.. 10cm though
2020-02-27 Voltmeter circuitry and RL values
2020-02-28 Battery figurings
    [lipo-dimensions.xlsx]
2020-03-01 Building circuit, w/ Arduino Nano
    [motherboard.brd, motherboard.sch]
2020-03-03 Think I've got the circuitry down, boarding next
    [motherboard.brd, motherboard.sch]
2020-03-04 PCB coming along nicely
    [motherboard.brd, motherboard.sch]
2020-03-04 Finished the PCB.. and then decided I should split the display/buttons separately
    [motherboard.brd, motherboard.sch]
2020-03-05 Getting to be quite a serious design..
    [motherboard.brd, motherboard.sch]
2020-03-06 Library parts are annoying
    [motherboard.brd, motherboard.sch]
2020-03-06 Motherboard complete!
    [motherboard.brd, motherboard.sch]
2020-03-06 Okay _now_ I'm happy with the motherboard
    [motherboard.brd]
2020-03-07 Real life is gritty! - Etching at this point
    [motherboard.brd, motherboard.sch]
2020-03-23 Re-organising for Chokia mk II
    [motherboard.brd, motherboard.sch]
2020-03-23 Chokia platformio - STM32
2020-03-23 Happy with that as an LCD test
    [motherboard.brd]
2020-03-24 Chokia sends. Pager receives. Not vice-versa...
    [motherboard.brd, motherboard.sch]
2020-03-24 Pin mistake? was that all it was?
    [main.cpp]
2020-03-24 Eagle grief and keycaps
    [ISO_enter.scad, alps.scad, bars.scad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]
2020-03-26 PCB trackin'
    [daughterboard.brd, motherboard.brd, motherboard.sch]
2020-03-26 Ready 2 etch dot com?
    [motherboard.brd, motherboard.sch]

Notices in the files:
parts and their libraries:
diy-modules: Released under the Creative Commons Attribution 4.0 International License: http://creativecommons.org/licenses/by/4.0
